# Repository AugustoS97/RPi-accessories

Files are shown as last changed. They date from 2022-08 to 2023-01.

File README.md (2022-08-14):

# RPi-accessories

Repositorio con diferentes PCBs de uso con Arduino y Rapsberry

## Contenido del repositorio

- [PCB para control PWM](/PWM-TRANSISTOR-PCB/) de elementos de tensión igual o superior a la de alimentación del microcontrolador. Compatible con Arduino, Raspberry, ESP, etc.

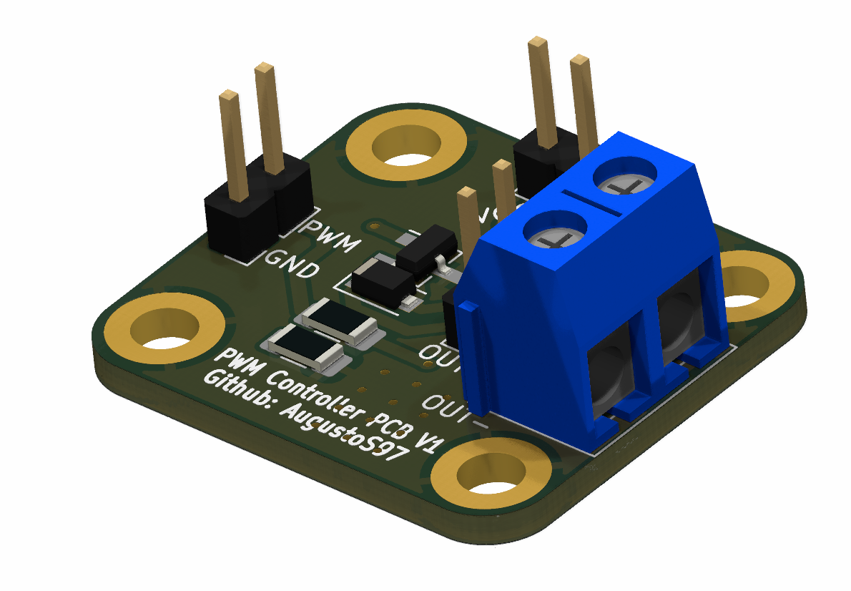
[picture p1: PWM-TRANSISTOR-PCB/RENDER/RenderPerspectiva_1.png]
Imagen PCB control PWM


- [PCB de expansión para Rapsberry](/LED-RPi-PCB/). Permite alimentar RPi desde fuente externa, conectar un elementos para control PWM (ventilador por ejemplo), LEDs de estado, fusible de protección y pines de expansión para alimentación.

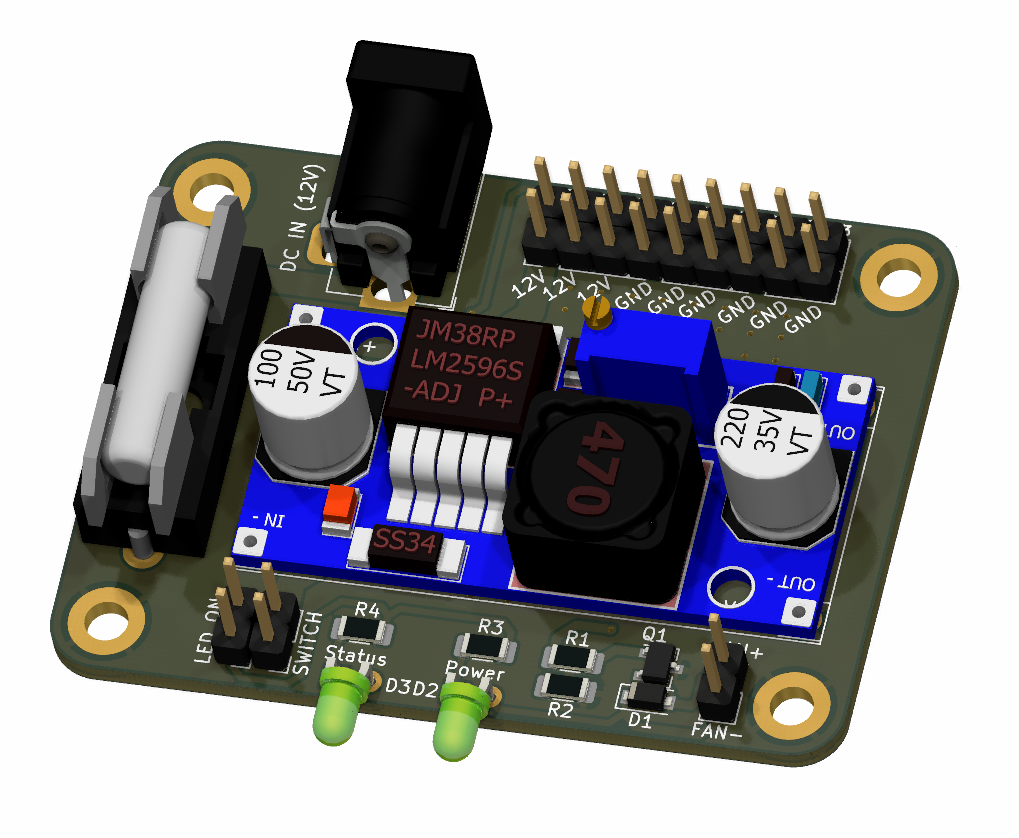
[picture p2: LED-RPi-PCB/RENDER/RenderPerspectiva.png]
Imagen PCB para expansion RPI


## Como ordenar las PCB

- Cada subproyecto dispone de una carpeta GERBER para ser subida a JLCPCB o PCBWAY y poder pedir las placas. Puedes adquirirse individualmente y soldadas contactando conmigo vía email: augustosamuelhdezmartin@gmail.com
- Existe una carpeta con GERBER para el panelizado de las PCB para ahorrar costes en JLCPCB.

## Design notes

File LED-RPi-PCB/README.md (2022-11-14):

# PWM-RPi-PCB

Módulo de expansión para Rapsberry Pi. Permite alimentar RPi desde una fuente externa superior a 5V, incorpora un módulo para control PWM de una salida, LEDs indicadores de Estado y de Alimentación, Fusible de Protección, y pines de expansión para aumentar las conexiones de 3.3V y 5V. Diseñado para ser utilizado en el [NAS expuesto aquí](https://github.com/AugustoS97/Raspberry-Pi-NAS).

Render Perspectiva

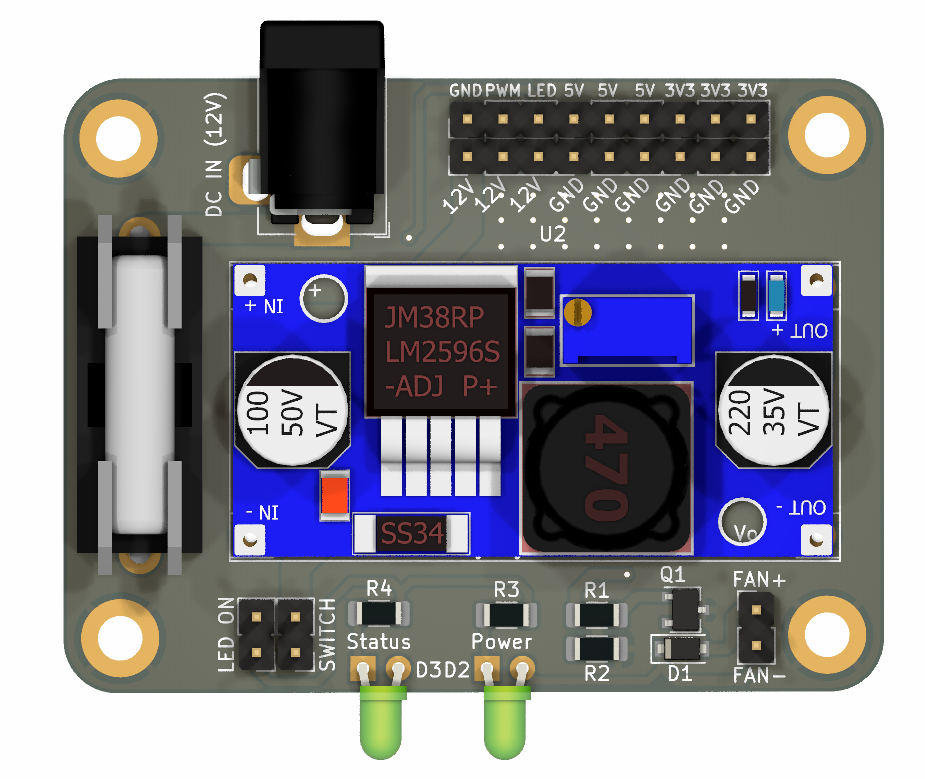
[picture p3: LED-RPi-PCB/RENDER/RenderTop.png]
Render TOP


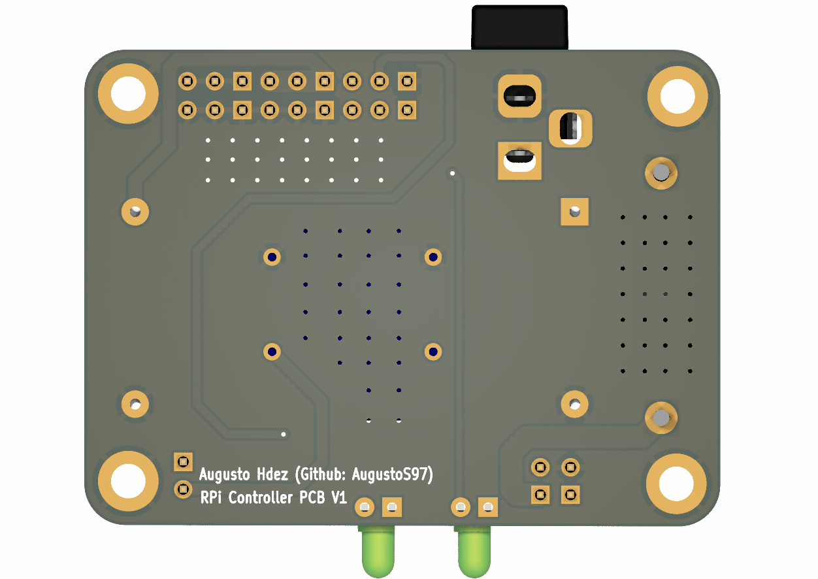
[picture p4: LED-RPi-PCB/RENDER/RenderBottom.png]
Render TOP


## Características

- Permite alimentar RPi desde una fuente externa superior a 5V con módulos LM2596 y MP2307
- Incorpora un módulo para control PWM de una salida de hasta 625mW
- LEDs indicadores de Estado y de Alimentación
- Fusible de Protección 5x20
- Pines de expansión para aumentar las conexiones de 3.3V y 5V
- Cuenta con Jumper (JP2) para desactivar o activar los LEDs indicadores
- Incorpora un Jumper/Pines (JP1) para conectar un interruptor de encendido y apagado del módulo mediante conectores Dupont
- Dimensiones 58,7mm x 43,9mm
- GERBER disponibles para solicitar las PCB. Si desea comprarlas ensambladas por unidades, puedes contactarme a augustosamuelhdezmartin@gmail.com

## Características de la salida PWM 

- Corriente máxima: 600mA
- Potencia máxima: 625mW
- Pensado para controlar motores desde Raspberry y Arduino (3,3V y 5V de señal de control). Puede modificarse R1 y R2 para ser utilizado con otras tensiones de control.

## Lista de materiales (BOM)

- Transistor 2N2222A SOT-23
- Resistencia 1206 1K 0.25W x2 unidades
- Resistencia 1206 10K 0.25W
- Resistencia 1206 220Ohm 
- Módulo DC/DC MP2307 o LM2596
- Diodo 1N4007 SOD-123F
- PinHeader 2.54mm 9 pines x2 unidades
- Portafuisble 5x20
- Jumpers x2 unidades
- LED 5mm x2 unidades (rojo y verde)
- PinHeader 2.54mm 2 pines x3 unidades
- Conector DC-Jack

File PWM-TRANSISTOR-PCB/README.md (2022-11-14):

# PWM-TRANSISTOR-PCB

Módulo para el control PWM de cualquier elemento que trabaje con tensión igual o superior a la de alimentación.

Render Perspectiva

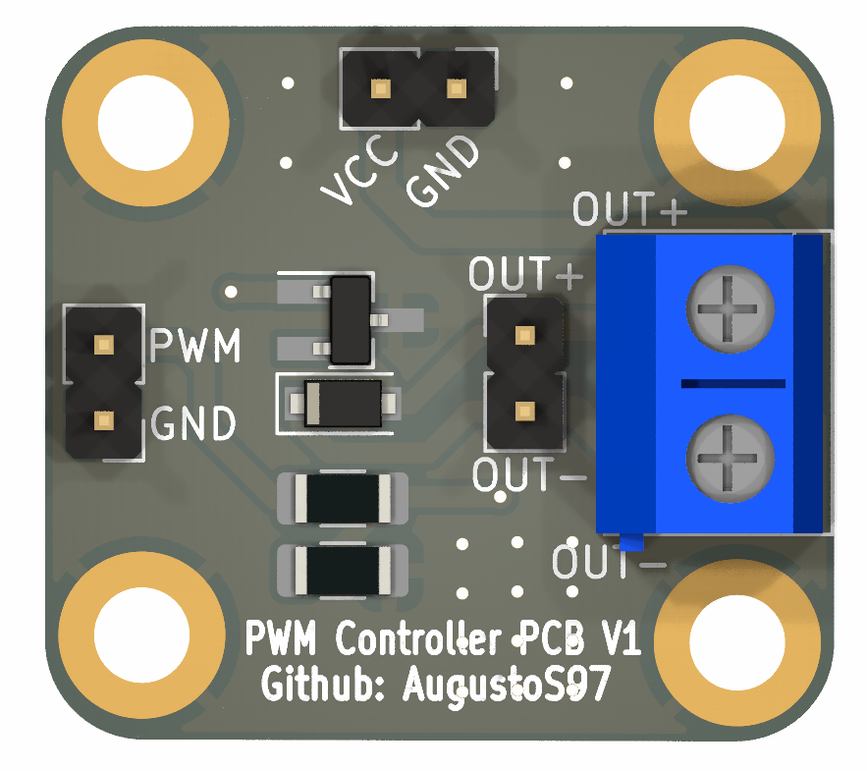
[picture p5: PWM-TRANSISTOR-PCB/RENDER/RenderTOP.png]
Render TOP


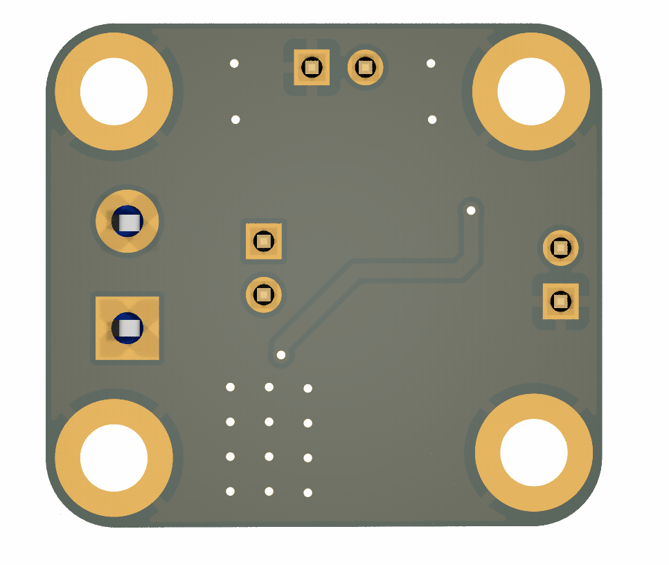
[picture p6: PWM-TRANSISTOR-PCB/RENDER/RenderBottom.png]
Render TOP


- Corriente máxima: 600mA
- Potencia máxima: 625mW
- Pensado para controlar motores desde Raspberry y Arduino (3,3V y 5V de señal de control). Puede modificarse R1 y R2 para ser utilizado con otras tensiones de control.
- GERBER disponibles para solicitar las PCB. Si desea comprarlas ensambladas por unidades, puedes contactarme a augustosamuelhdezmartin@gmail.com
- Dimensiones de la PCB 26,7mm x 23,9 mm.

## Lista de materiales (BOM)

- Transistor 2N2222A SOT-23
- Resistencia 1206 1K 0.25W
- Resistencia 1206 10K 0.25W
- Diodo 1N4007 SOD-123F
- PinHeader 2.54 2 pines x3 unidades
- Terminal Block 5.08mm

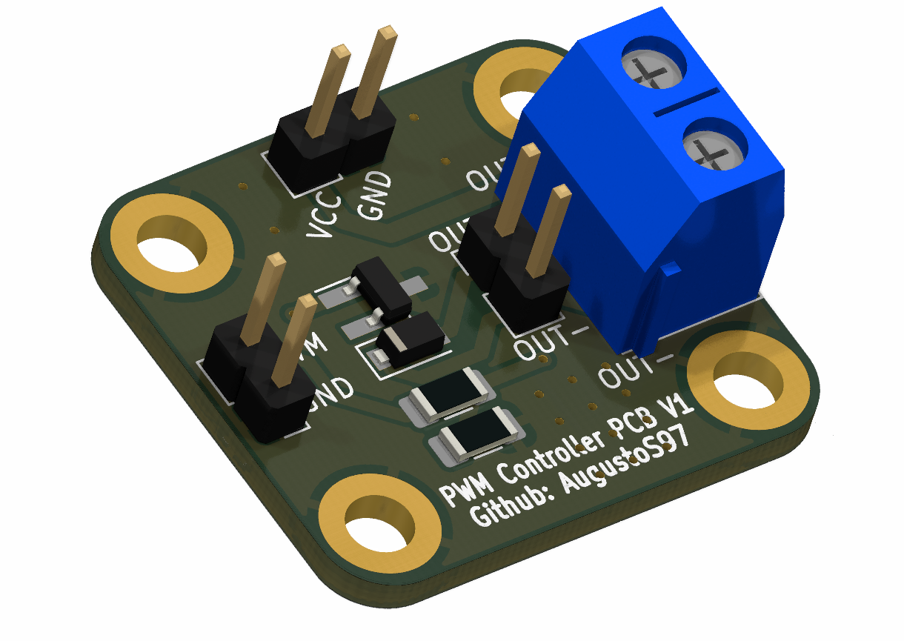
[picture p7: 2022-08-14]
PWM-TRANSISTOR-PCB/RENDER/RenderPerspectiva_2.png

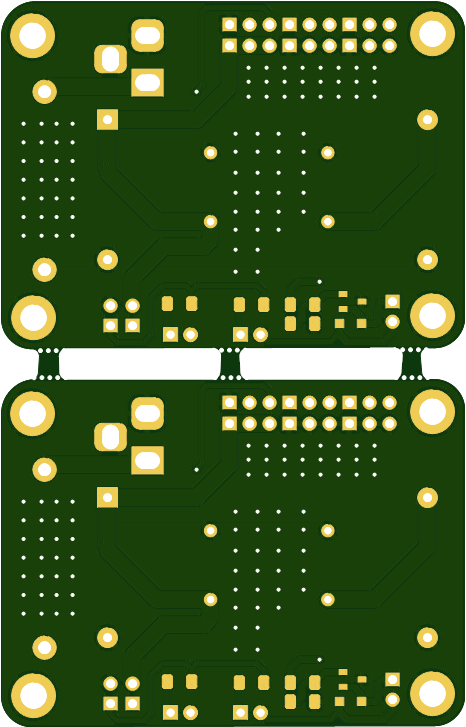
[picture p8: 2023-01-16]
LED-RPi-PCB/Gerber/Panelizado/Untitled_Combined_Top.png

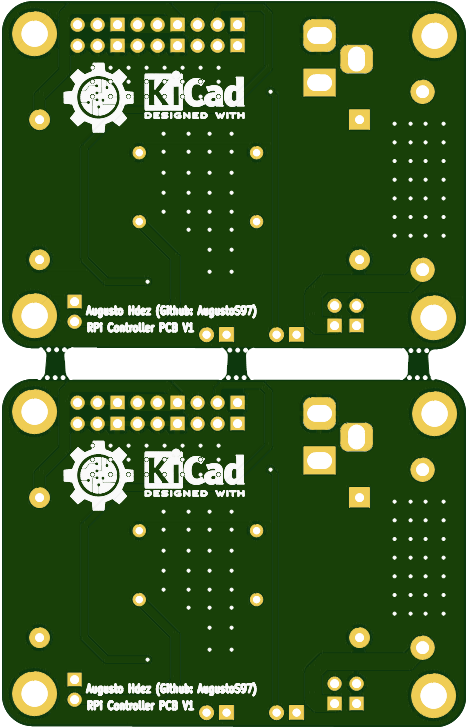
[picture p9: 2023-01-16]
LED-RPi-PCB/Gerber/Panelizado/Untitled_Combined_Bottom.png

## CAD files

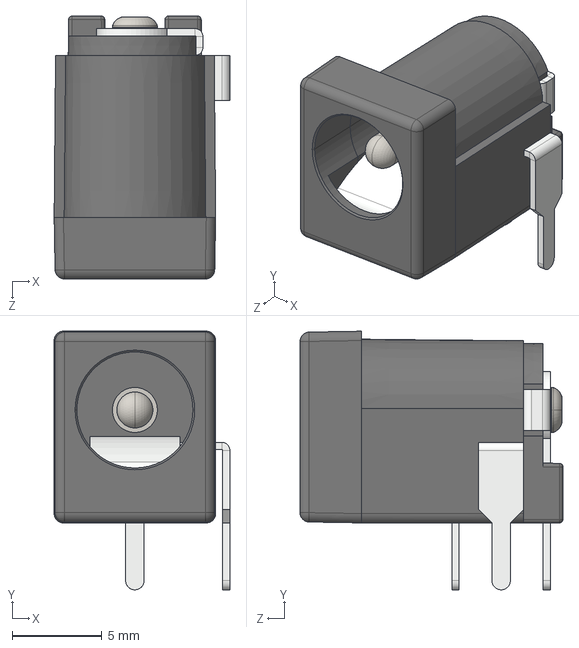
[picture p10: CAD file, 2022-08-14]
LED-RPi-PCB/STEP/DC Power Jack 5.5mm x 2.1mm.STEP
9.77 x 14.4 x 14.6 mm

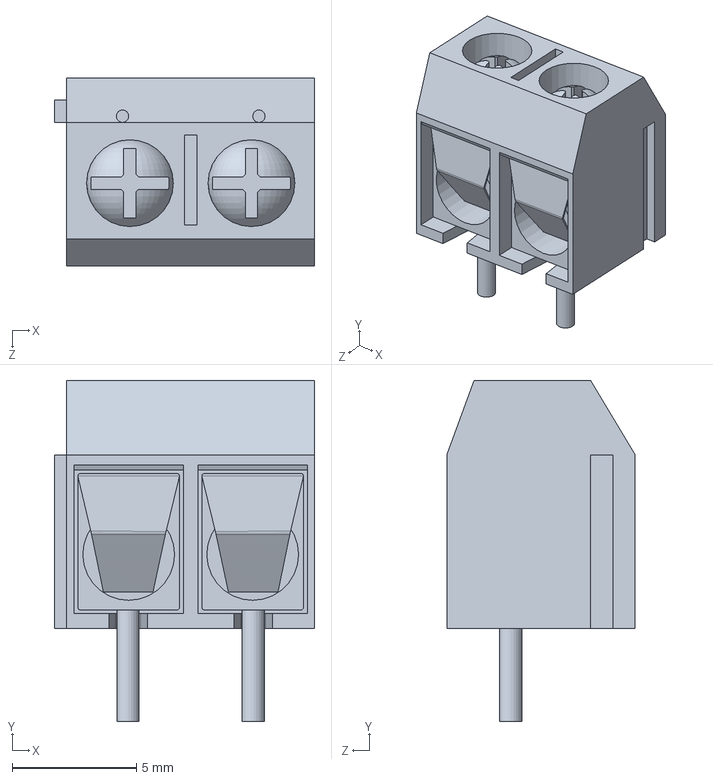
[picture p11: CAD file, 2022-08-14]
PWM-TRANSISTOR-PCB/STEP/bornera.SLDPRT
10.5 x 13.8 x 7.60 mm

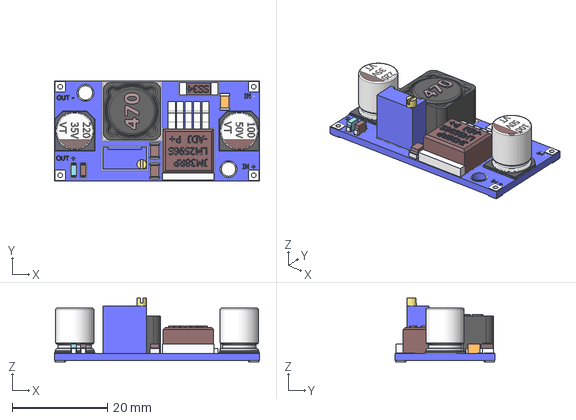
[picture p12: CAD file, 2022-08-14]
LED-RPi-PCB/STEP/lm2596.stp
43.0 x 21.0 x 13.3 mm

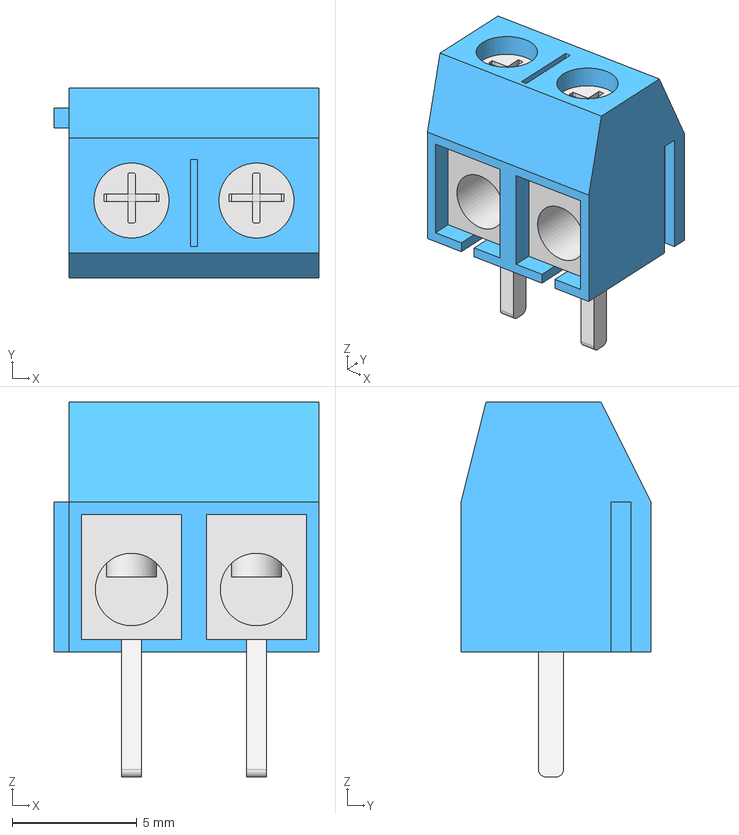
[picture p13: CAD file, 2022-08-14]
PWM-TRANSISTOR-PCB/STEP/Terminal block 5mm.step
10.6 x 7.60 x 15.0 mm
Tornillos001

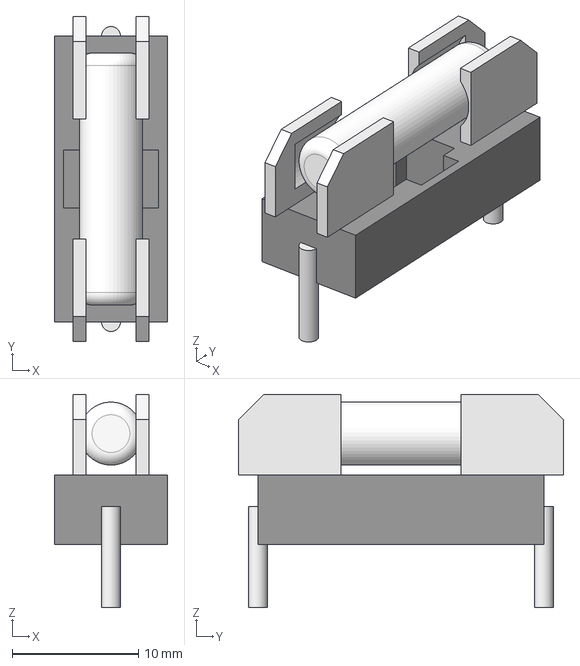
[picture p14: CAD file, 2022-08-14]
LED-RPi-PCB/STEP/LITTELFUSE_FuseBlock_646_v3.step
9.00 x 25.8 x 16.9 mm

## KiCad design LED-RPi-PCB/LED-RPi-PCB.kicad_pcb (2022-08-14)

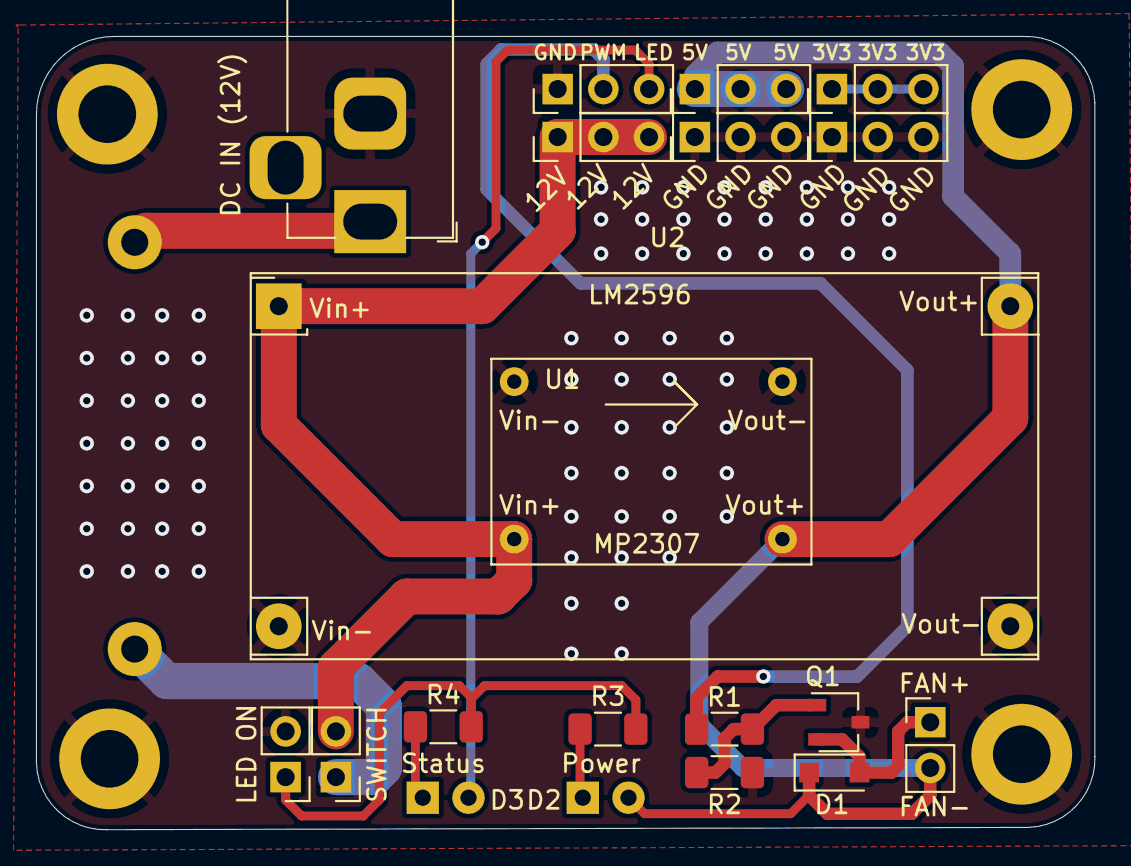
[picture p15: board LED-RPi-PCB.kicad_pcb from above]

Board: 2 copper layers, 58.8 x 44.1 mm, 25 parts (0 on the bottom side), 13 nets.

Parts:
D1: 1N4007; D_SOD-123F
D2: RED; LED_D3.0mm_Horizontal_O1.27mm_Z2.0mm
D3: YELLOW; LED_D3.0mm_Horizontal_O1.27mm_Z2.0mm
F1: 1,5A; Fuseholder_Cylinder-5x20mm_Stelvio-Kontek_PTF78_Horizontal_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
H1, H2, H3, H4: MountingHole_Pad; MountingHole_3.2mm_M3_DIN965_Pad
J1: FAN_CON; PinHeader_1x02_P2.54mm_Vertical
J2: RPi_IN; PinHeader_1x03_P2.54mm_Vertical
J3, J8: GND_CON; PinHeader_1x03_P2.54mm_Vertical
J4: 12V_CON; PinHeader_1x03_P2.54mm_Vertical
J5: 5V_CON; PinHeader_1x03_P2.54mm_Vertical
J6: 3V3_CON; PinHeader_1x03_P2.54mm_Vertical
J7: Jack-DC; BarrelJack_Horizontal
JP1: Jumper & Switch; PinHeader_1x02_P2.54mm_Vertical
JP2: LED_ON; PinHeader_1x02_P2.54mm_Vertical
Q1: 2N2222A; SOT-23W
R1, R3: 1k; R_1206_3216Metric_Pad1.30x1.75mm_HandSolder
R2: 10k; R_1206_3216Metric_Pad1.30x1.75mm_HandSolder
R4: 220; R_1206_3216Metric_Pad1.30x1.75mm_HandSolder
U1: MP2307
U2: DCDC_StepDown_LM2596

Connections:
+3V3: J6.1, J6.2, J6.3
+5V: D1.1, D2.2, J1.2, J5.1, J5.2, J5.3, U1.3, U2.4
+12V: J4.1, J4.2, J4.3, JP1.2, U1.1, U2.1
/FAN_V-: D1.2, J1.1, Q1.2
GND: H1.1, H2.1, H3.1, H4.1, J2.1, J3.1, J3.2, J3.3, J7.2, J8.1, J8.2, J8.3, JP2.2, Q1.3, R2.2, U1.2, U1.4, U2.2, U2.3
unnamed: D2.1, R3.1
unnamed: D3.1, R4.1
unnamed: F1.1, JP1.1
unnamed: JP2.1, R3.2, R4.2
unnamed: Q1.1, R1.1, R2.1
PWM: J2.2, R1.2
StatusLED+: D3.2, J2.3
VDC: F1.2, J7.1

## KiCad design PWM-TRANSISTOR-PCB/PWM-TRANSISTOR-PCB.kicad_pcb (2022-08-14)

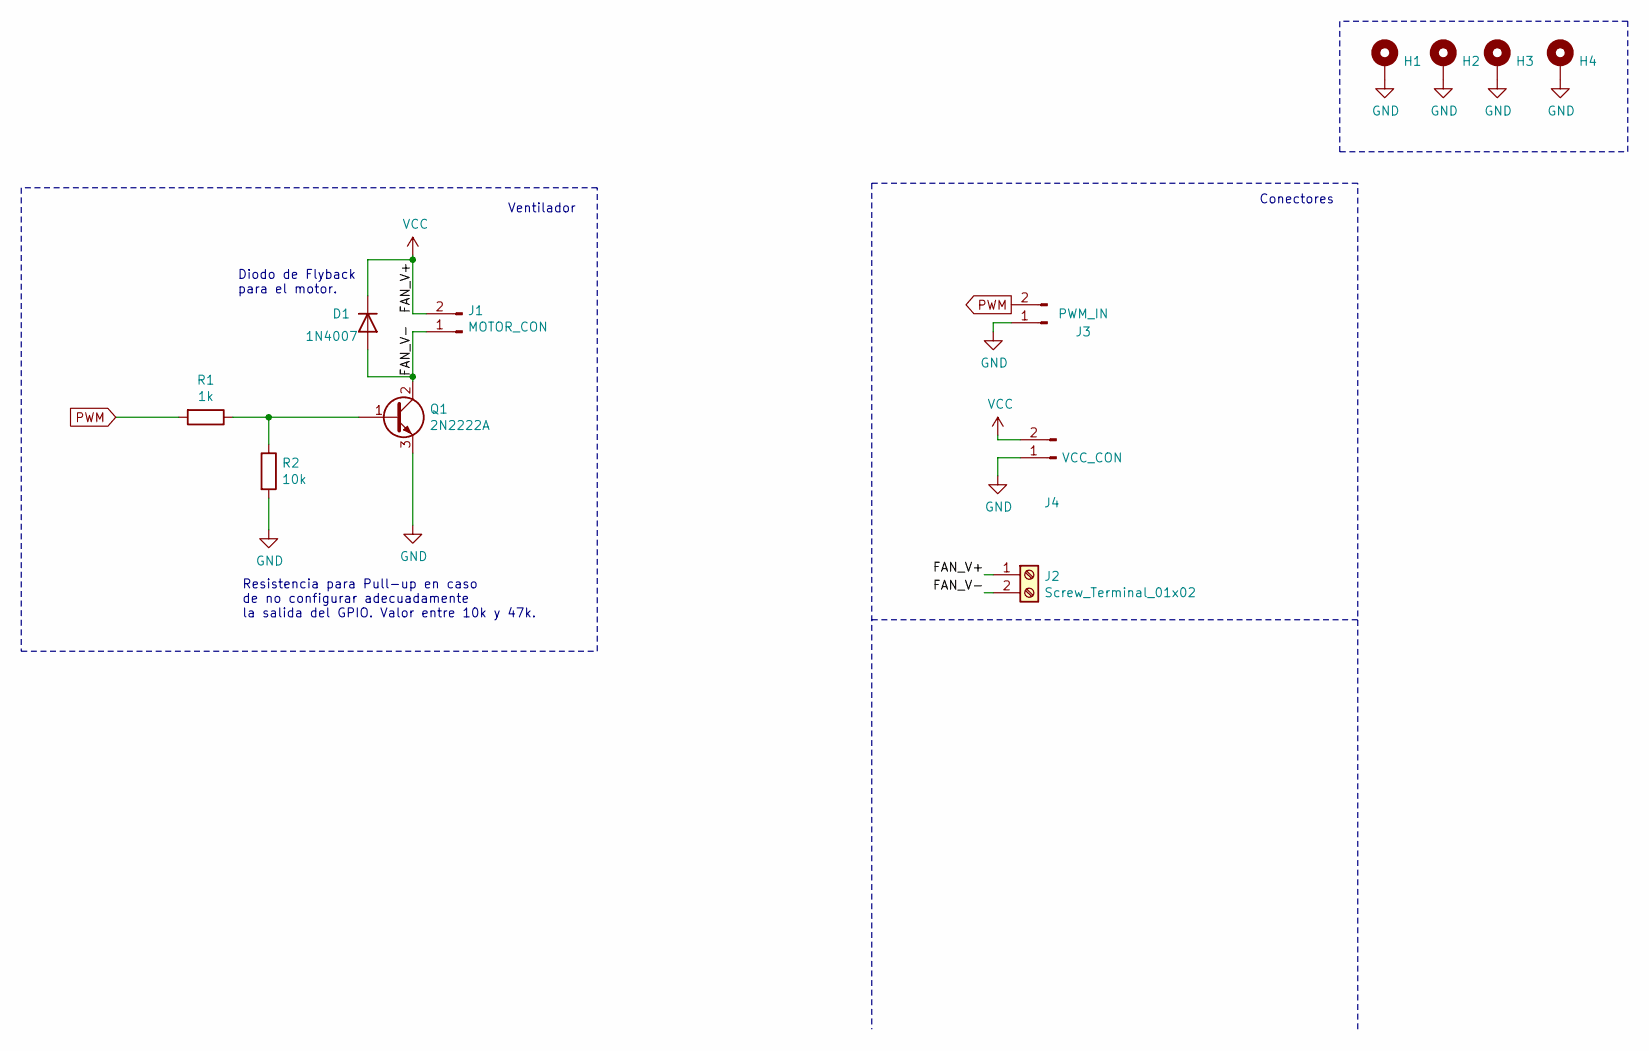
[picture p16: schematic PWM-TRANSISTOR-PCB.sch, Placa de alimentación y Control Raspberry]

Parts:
D1: 1N4007; D_SOD-123F
H1, H2, H3, H4: MountingHole_Pad; MountingHole_3.2mm_M3_DIN965_Pad
J1: MOTOR_CON; PinHeader_1x02_P2.54mm_Vertical
J2: Screw_Terminal_01x02; TerminalBlock_bornier-2_P5.08mm
J3: PWM_IN; PinHeader_1x02_P2.54mm_Vertical
J4: VCC_CON; PinHeader_1x02_P2.54mm_Vertical
Q1: 2N2222A; SOT-23_Handsoldering
R1: 1k; R_1206_3216Metric_Pad1.30x1.75mm_HandSolder
R2: 10k; R_1206_3216Metric_Pad1.30x1.75mm_HandSolder

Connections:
/FAN_V-: D1.2 (A), J1.1, J2.2, Q1.2 (C)
GND: H1.1, H2.1, H3.1, H4.1, J3.1, J4.1, Q1.3 (E), R2.2
unnamed: Q1.1 (B), R1.1, R2.1
PWM: J3.2, R1.2
VCC: D1.1 (K), J1.2, J2.1, J4.2

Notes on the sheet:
Resistencia para Pull-up en caso de no configurar adecuadamente la salida del GPIO. Valor entre 10k y 47k.
Diodo de Flyback para el motor.
Conectores
Ventilador

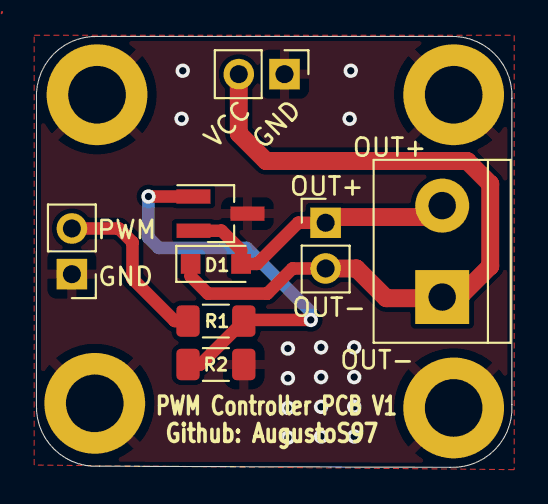
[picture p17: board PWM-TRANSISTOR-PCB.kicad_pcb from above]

Board: 2 copper layers, 26.4 x 23.9 mm, 12 parts (0 on the bottom side), 5 nets.

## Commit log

2022-06-15 Creada la version V1.0 de la PCB para DCDC, ventilador y LEDs
    [LED-RPi-PCB.kicad_pcb, LED-RPi-PCB.sch]
2022-07-15 Creada PCB para controlar motores con PWM y Transistor. Añadidos logos DCD
    [LED-RPi-PCB-B_Cu.gbl, LED-RPi-PCB-B_Mask.gbs, LED-RPi-PCB-B_Paste.gbp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]
2022-08-14 Añadidos las README así como GERBERS y RENDERs
    [DC Power Jack 5.5mm x 2.1mm.STEP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]
2022-11-14 Añadido STEP de PCB
2023-01-16 Añadido panelizado de PCB.
    [combined.drl, combined.gbl, combined.gbo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]
